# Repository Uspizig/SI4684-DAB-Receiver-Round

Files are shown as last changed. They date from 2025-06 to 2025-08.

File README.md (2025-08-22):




# Note:
The version in the repository is an ongoing development. It could and will contain bugs. To make sure you use the latest fully tested firmware, check the releases!

# Hint:
#define USE_HSPI_PORT ... set this to active in eTFT Lib user_setup.h. otherwise it won't work

# SI4684 DAB receiver
Advanced DAB Tuner software for Skyworks SI4684 tuner with ESP32 board and a round color LCD or AMOLED\
This is a fork of the famous PE5PVB SI4684 Project, unfinished and right now still in devolpment.
Check a more developed project on the origin source: https://www.pe5pvb.nl/

# How does it look

Simulation
<p align="center"> 
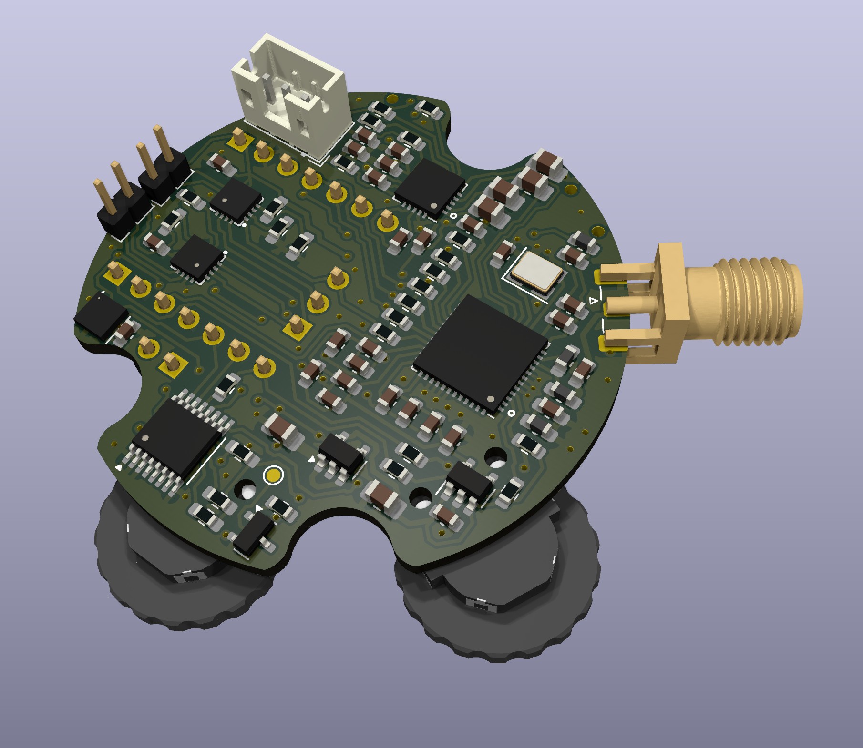
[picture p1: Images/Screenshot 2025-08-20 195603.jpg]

</p>

Real device
<p align="center"> 
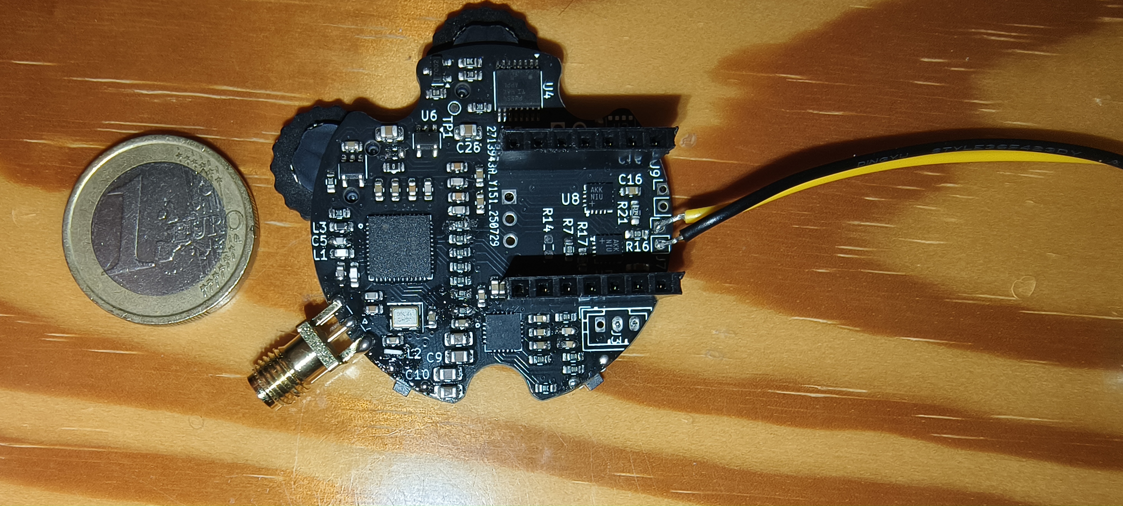
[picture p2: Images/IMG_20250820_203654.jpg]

</p>

# How does it look working

These are pictures of the very first HW bringup

<p align="center"> 
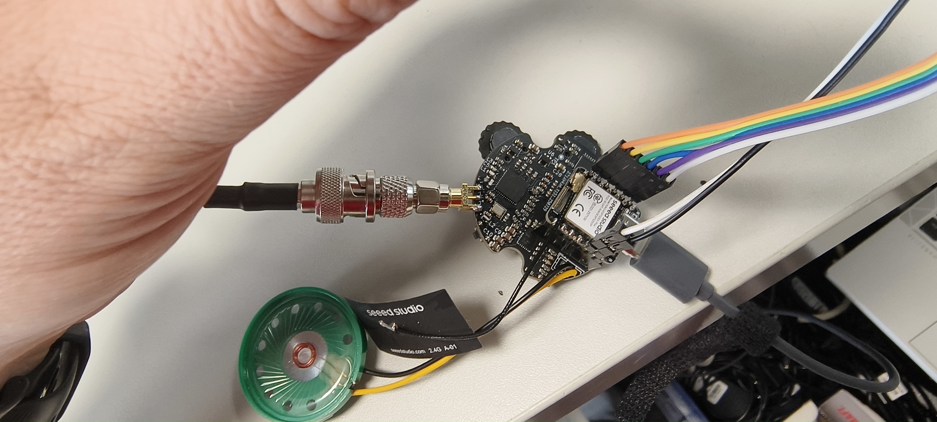
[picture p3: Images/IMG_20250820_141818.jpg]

</p>

Base Screen:
<p align="center"> 
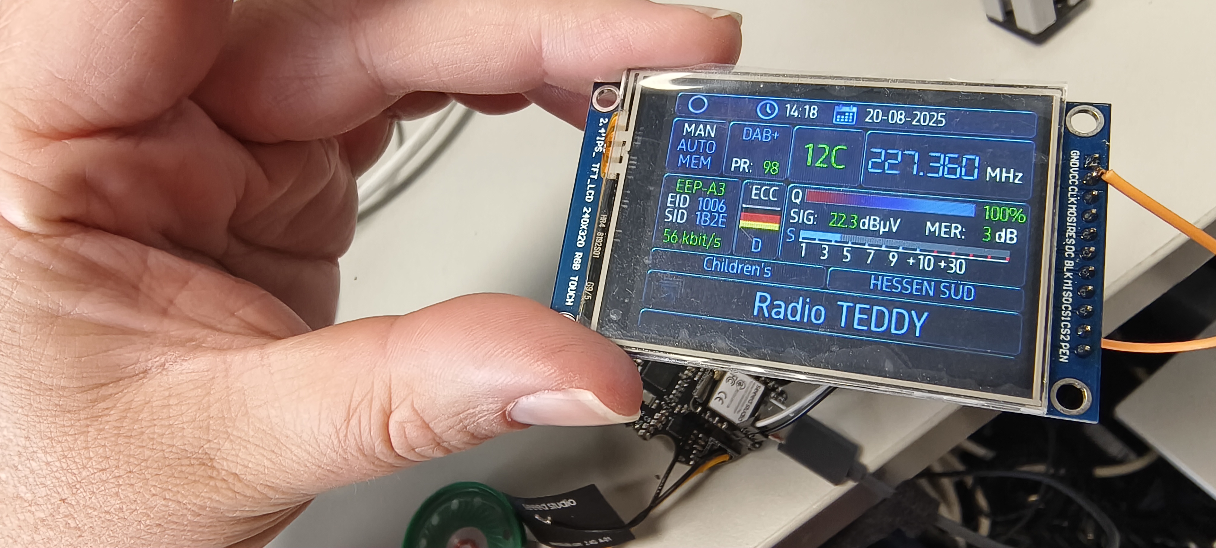
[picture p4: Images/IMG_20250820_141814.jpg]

</p>

DAB Slideshow
<p align="center"> 
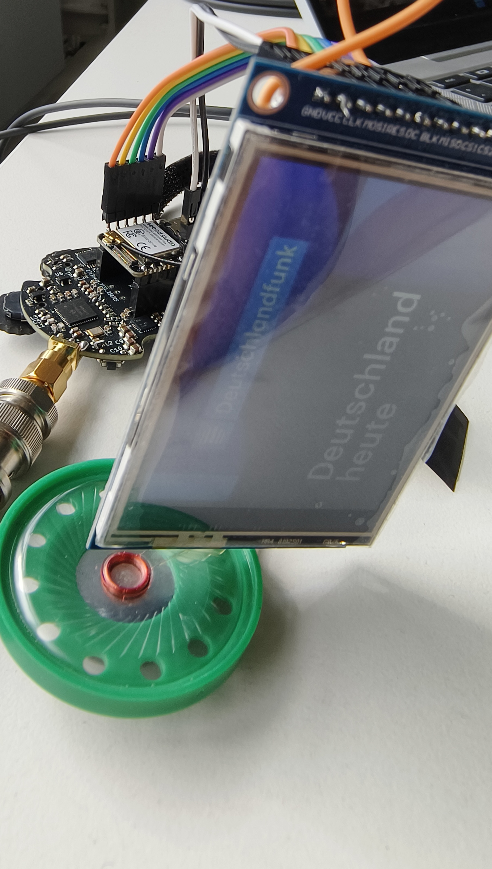
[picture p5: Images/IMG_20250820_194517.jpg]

</p>

# Libraries
These are the libraries used for this project:
- https://github.com/Bodmer/TFT_eSPI
- https://github.com/uzi18/TFT_eSPI
- https://github.com/Bodmer/JPEGDecoder
- https://github.com/bitbank2/PNGdec

Use these settings in the TFT_eSPI library:
```
#define ILI9341_2_DRIVER     // Alternative ILI9341 driver, see https://github.com/Bodmer/TFT_eSPI/issues/1172
#define TFT_WIDTH  240 // ST7789 240 x 240 and 240 x 320
#define TFT_HEIGHT 320 // ST7789 240 x 320

#define TFT_CS    38  // Chip select PIN
#define TFT_MISO  39  // MISO PIN
#define TFT_DC    40  // Data Command control pin
#define TFT_RST   41  // Reset pin (could connect 
#define TFT_MOSI  42  // MOSI PIN
#define TFT_SCLK  10  // CLK PIN
#define SPI_FREQUENCY  27000000
#define SMOOTH_FONT
#define USE_HSPI_PORT ///// THIS IS IMPORTANT OTHERWISE NO CONTACT TO DAB TUNER
#define LOAD_GFXFF  // FreeFonts. Include access to the 48 Adafruit_GFX free fonts FF1 to FF48 and custom fonts
#define SPI_READ_FREQUENCY  20000000
#define SPI_TOUCH_FREQUENCY  2500000

```
# Buttons
A brief instruction for the buttons:
- Top encoder: Choose frequency or memory channel
- Bottom encoder: Choose service or set headphones volume
- (Not in use right now) Top button: Short press: Service information, Long press: Stand-by mode. 
- Middle button: Short press: Set mode, Long press: Open menu.
- Lower button: Toggle Slideshow view.
  
## Contributing
I'm open for a new ideas in our project. Feel free to share your thoughts in 

You are using my software and you found a difficulty? Please create new [issue] and describe your problem.

I also would like to invite you to join our Discord community where we share our ideas and help each other with some issues.\
[Join the TEF6686 Discord community!](https://discord.gg/ZAVNdS74mC)  

Special thanks to all [contributors](https://github.com/PE5PVB/TEF-Nextion-Multiband/graphs/contributors). You are awesome! ❤️
## License
This program is free software; you can redistribute it and/or modify it under the terms of the GNU General Public License as published by the Free Software Foundation; either version 3 of the License, or (at your option) any later version.

This program is distributed in the hope that it will be useful, but WITHOUT ANY WARRANTY; without even the implied warranty of MERCHANTABILITY or FITNESS FOR A PARTICULAR PURPOSE. See the GNU General Public License for more details. 

## If you like this software. Contriubute to 


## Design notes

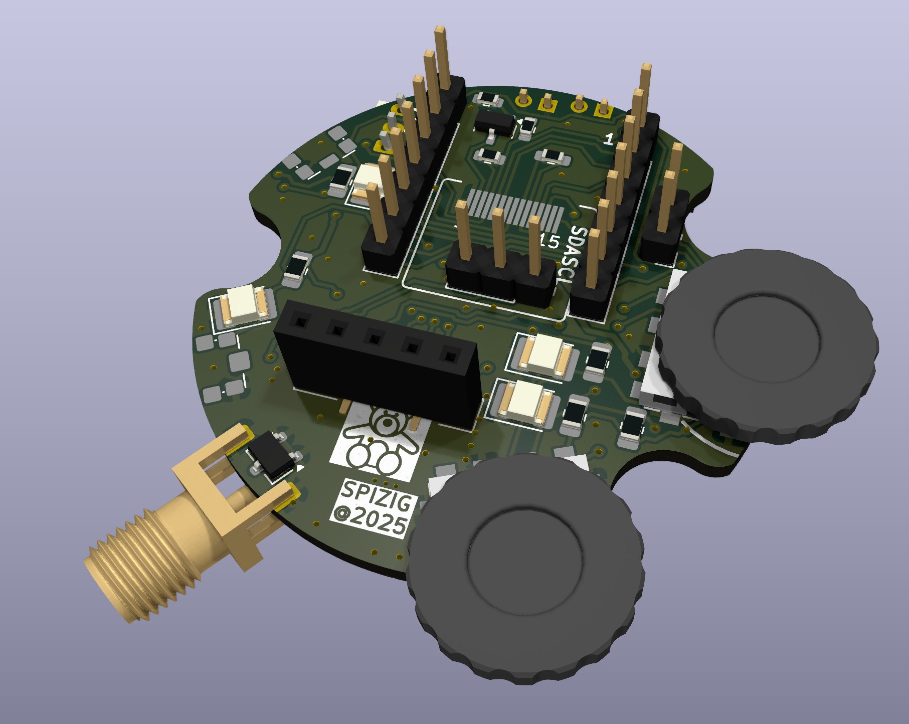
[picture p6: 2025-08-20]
Images/Screenshot 2025-08-20 195328.jpg

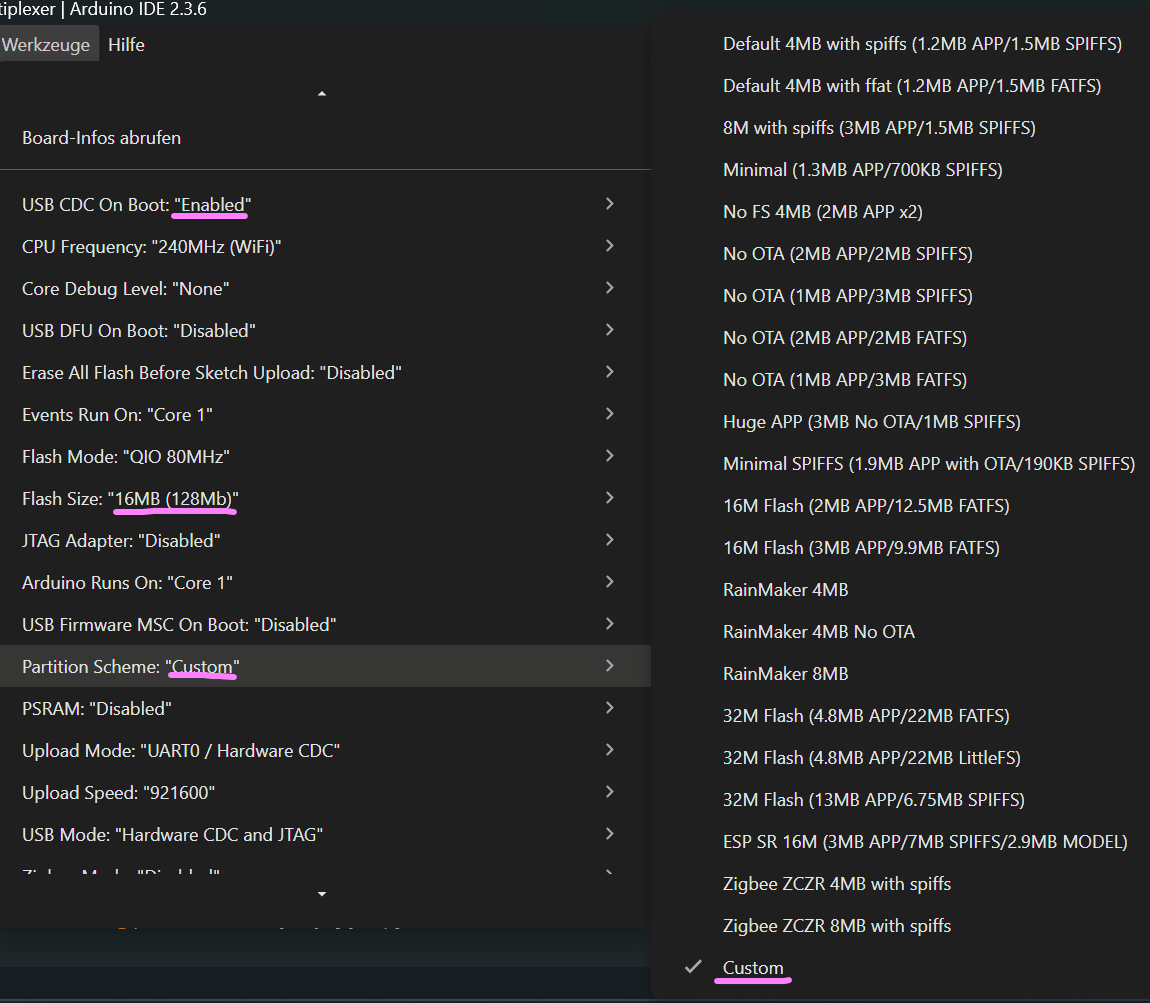
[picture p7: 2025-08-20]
Images/config.png

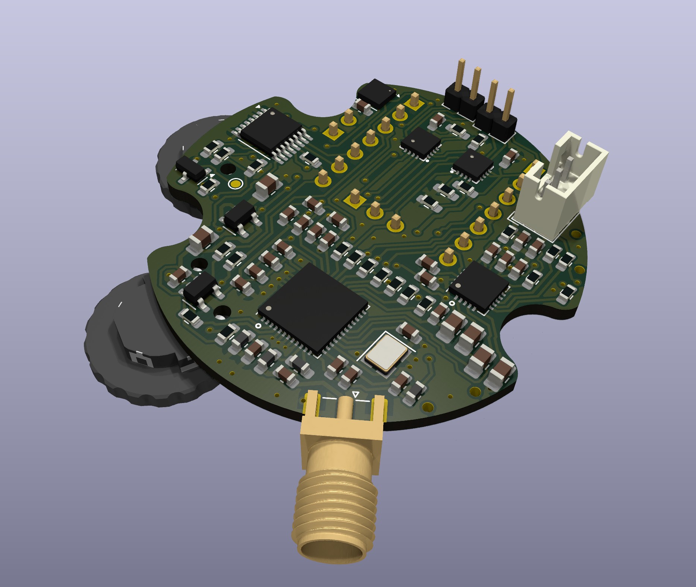
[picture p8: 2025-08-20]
Images/Screenshot 2025-08-20 195246.jpg

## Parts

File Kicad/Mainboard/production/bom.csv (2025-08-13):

Designator | Footprint | Quantity | Value | LCSC Part #
ANT | SMA_Samtec_SMA-J-P-H-ST-EM1_EdgeMount | 1 | Antenna_Shield
C1, C14, C15, C16, C17, C20, C26, C35, C4, C41 | 0603 | 10 | 1uF
C10, C11, C8, C9 | 0805 | 4 | 10uF
C12, C23, C29, C38 | 0603 | 4 | 8p2
C18, C19, C21, C24, C6 | 0603 | 5 | 100n
C22 | 0603 | 1 | 100nF
C25, C30, C40, C7 | 0603 | 4 | 2n2
C28, C31 | 0805 | 2 | 1uF
C3 | 0603 | 1 | 33p
C34, C39 | 0603 | 2 | 270p
C5 | 0603 | 1 | 2p7
D1 | SOT-23W | 1 | BAV99
D2, D3, D4, D5 | 1210 | 4 | LED
J1 | PinHeader_1x03_P2.54mm_Vertical | 1 | Conn_01x03
J2 | PinSocket_1x05_P2.54mm_Vertical_SMD_Pin1Left | 1 | Conn_01x05
J3 | JST_PH_B3B-PH-K_1x03_P2.00mm_Vertical | 1 | Headphones
J5 | PinHeader_1x07_P2.54mm_Vertical | 1 | DISP LEFT
J6 | PinHeader_1x07_P2.54mm_Vertical | 1 | DISP RIGHT
J7, J9 | PinHeader_1x02_P2.00mm_Vertical | 2 | Conn_01x02_Pin
J8 | PinHeader_1x02_P2.54mm_Vertical | 1 | Conn_01x02_Pin
L1 | 0603 | 1 | 18nH
L2 | 0603 | 1 | BEAD
L3 | 0603 | 1 | 120nH
L4 | 0603 | 1 | 22nH
Q1, Q2 | SOT-23 | 2 | 2N7002
R1, R18, R25, R26, R30, R31, R32, R34 | 0603 | 8 | 10k
R10, R11, R15, R2, R20, R3, R4, R5, R8, R9 | 0603 | 10 | 100
R12, R13 | 0603 | 2 | 2k
R14 | 0603 | 1 | 3k
R16, R7 | 0603 | 2 | 100K
R17 | 0603 | 1 | 680K
R19 | 0603 | 1 | 1M
R21 | 0603 | 1 | 330K
R22 | 0603 | 1 | 22
R27, R28, R29, R35, R36 | 0805 | 5 | 10k
R33, R37 | 0603 | 2 | 0R
R6 | 0603 | 1 | 600
SW5, SW6 | SW_SPST_CK_KMS2xxGP | 2 | SW_Push
TP1 | TestPoint_Pad_D1.0mm | 1 | TestPoint
U1 | SOT-23-5 | 1 | MIC5504-1.8YM5
U12, U14 | SW-SMD_SIQ-02FVS3_1 | 2 | SIQ-02FVS3
U13 | GC9A01_Touch_IPS_display_reversed_16pin | 1 | ~
U2 | Bosch_LGA-8_3x3mm_P0.8mm_ClockwisePinNumbering | 1 | BME688
U3 | QFN-48-1EP_7x7mm_P0.5mm_EP5.3x5.3mm | 1 | SI4684-A10-GM
U4 | TSSOP-16_4.4x5mm_P0.65mm | 1 | TCA9554PW
U5 | QFN-20-1EP_4x4mm_P0.5mm_EP2.7x2.7mm | 1 | TPA6130A2RTJTR | TPA6130A2RTJTR
U6 | SOT-23-5 | 1 | RT9013
U7, U8 | TQFN-16_L3.0-W3.0-P0.50-BL-EP1.5 | 2 | MAX98357AETE
X1 | Crystal_SMD_3225-4Pin_3.2x2.5mm | 1 | S3219200071060

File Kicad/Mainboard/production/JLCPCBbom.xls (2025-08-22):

Comment | Designator | Footprint | JLCPCB Part #
22nH | L4 | 0603 | C90207
RT9013 | U6 | SOT-23-5 | C47773
1uF | C28,C31 | 0805 | C28323
2n2 | C25,C30,C40,C7 | 0603 | C1604
MIC5504-1.8YM5 | U1 | SOT-23-5 | C626116
330K | R21 | 0603 | C23137
MAX98357AETE | U7,U8 | TQFN-16_L3.0-W3.0-P0.50-BL-EP1.5 | C910544
100n | C22,C18,C19,C21,C24,C6 | 0603 | C14663
SI4684-A10-GM | U3 | QFN-48-1EP_7x7mm_P0.5mm_EP5.3x5.3mm | C1526088
2N7002 | Q1 | SOT-23 | C8545
TPA6130A2RTJTR | U5 | QFN-20-1EP_4x4mm_P0.5mm_EP2.7x2.7mm | C130046
2k | R12,R13 | 0603 | C22975
10uF | C10,C11,C8,C9 | 0805 | C15850
600 | R6 | 0603 | C23204
S3219200071060 | X1 | Crystal_SMD_3225-4Pin_3.2x2.5mm | C426975
8p2 | C12,C23,C29,C38 | 0603 | C1685
680K | R17 | 0603 | C25822
100 | R10,R11,R15,R2,R20,R3,R4,R5,R8,R9 | 0603 | C22775
18nH | L1 | 0603 | C48590
TCA9554PW | U4 | TSSOP-16_4.4x5mm_P0.65mm | C477924
120nH | L3 | 0603 | C275354
33p | C3 | 0603 | C1663
1uF | C1,C14,C15,C16,C17,C20,C26,C35,C4,C41 | 0603 | C15849
10k | R1,R25,R26,R30,R31,R32 | 0603 | C25804
0R | R33,R37 | 0603 | C21189
100K | R16,R7 | 0603 | C25803

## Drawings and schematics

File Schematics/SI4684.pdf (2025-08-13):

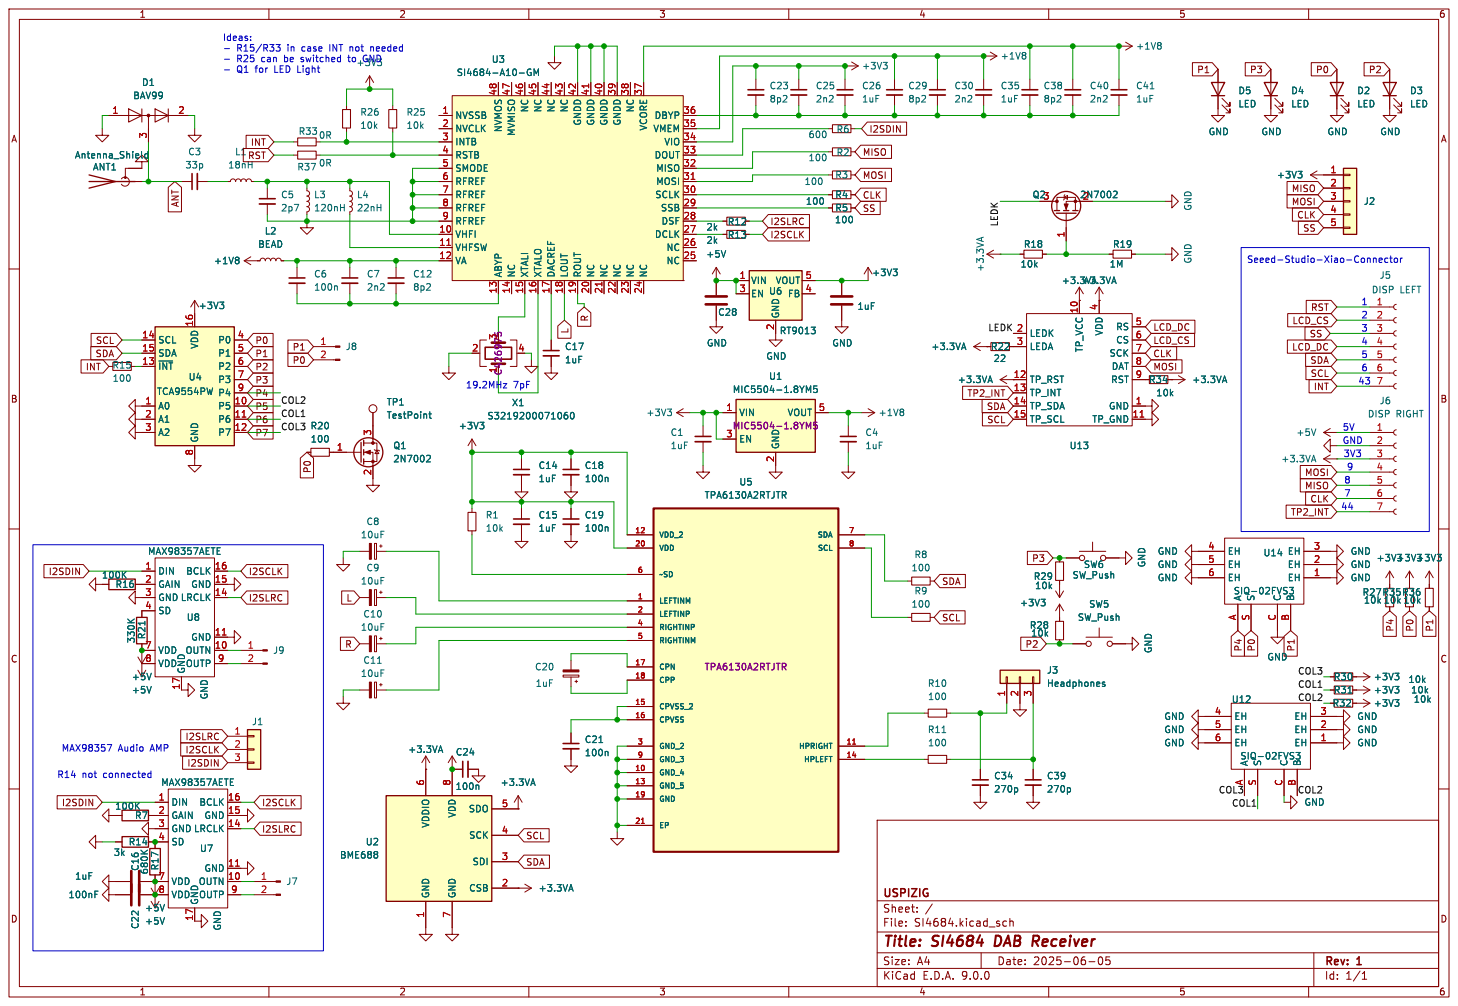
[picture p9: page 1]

J2 +1V8 TP1 TestPoint 1
- R25 can be switched to GND
- Q1 for LED Light

4 RS 5 CS 6 SCK 7 DAT 8 RST 9 GND 1 TP_GND 11 U13 R34 +3.3VA

4 RS 5 CS 6 SCK 7 DAT 8 RST 9 GND 1 TP_GND 11 R34 +3.3VA

B EH 3 EH 2 EH 1 U14 SIQ-02FVS3 GND

B EH 3 EH 2 EH 1 GND GND

B EH 3 EH 2 EH 1 U12SIQ-02FVS3 GND

B EH 3 EH 2 EH 1 GND

7 SDO 5 SCK 4 SDI 3 CSB 2 U2 BME688 C24

7 SDO 5 SCK 4 SDI 3 CSB 2 C24

Id: 1/1 Title: SI4684 DAB Receiver File: SI4684.kicad_sch Sheet: / USPIZIG

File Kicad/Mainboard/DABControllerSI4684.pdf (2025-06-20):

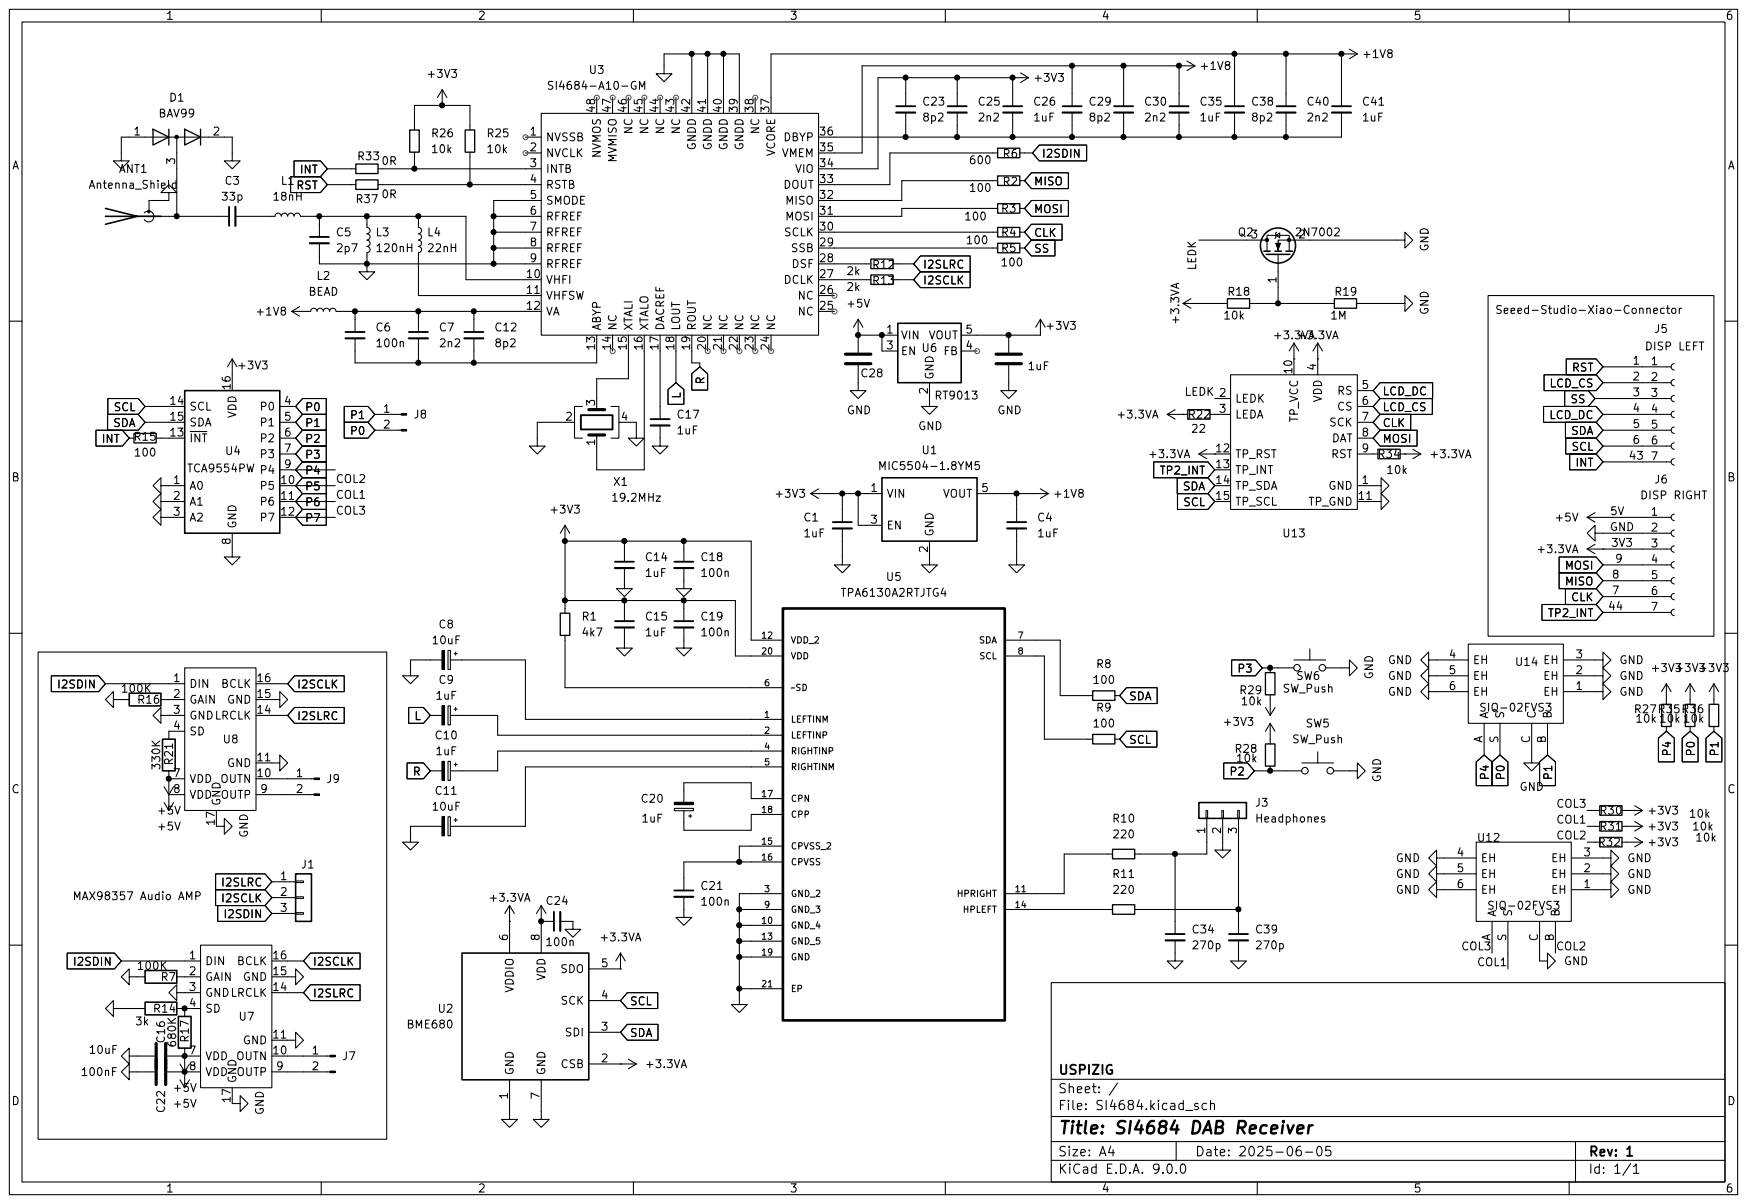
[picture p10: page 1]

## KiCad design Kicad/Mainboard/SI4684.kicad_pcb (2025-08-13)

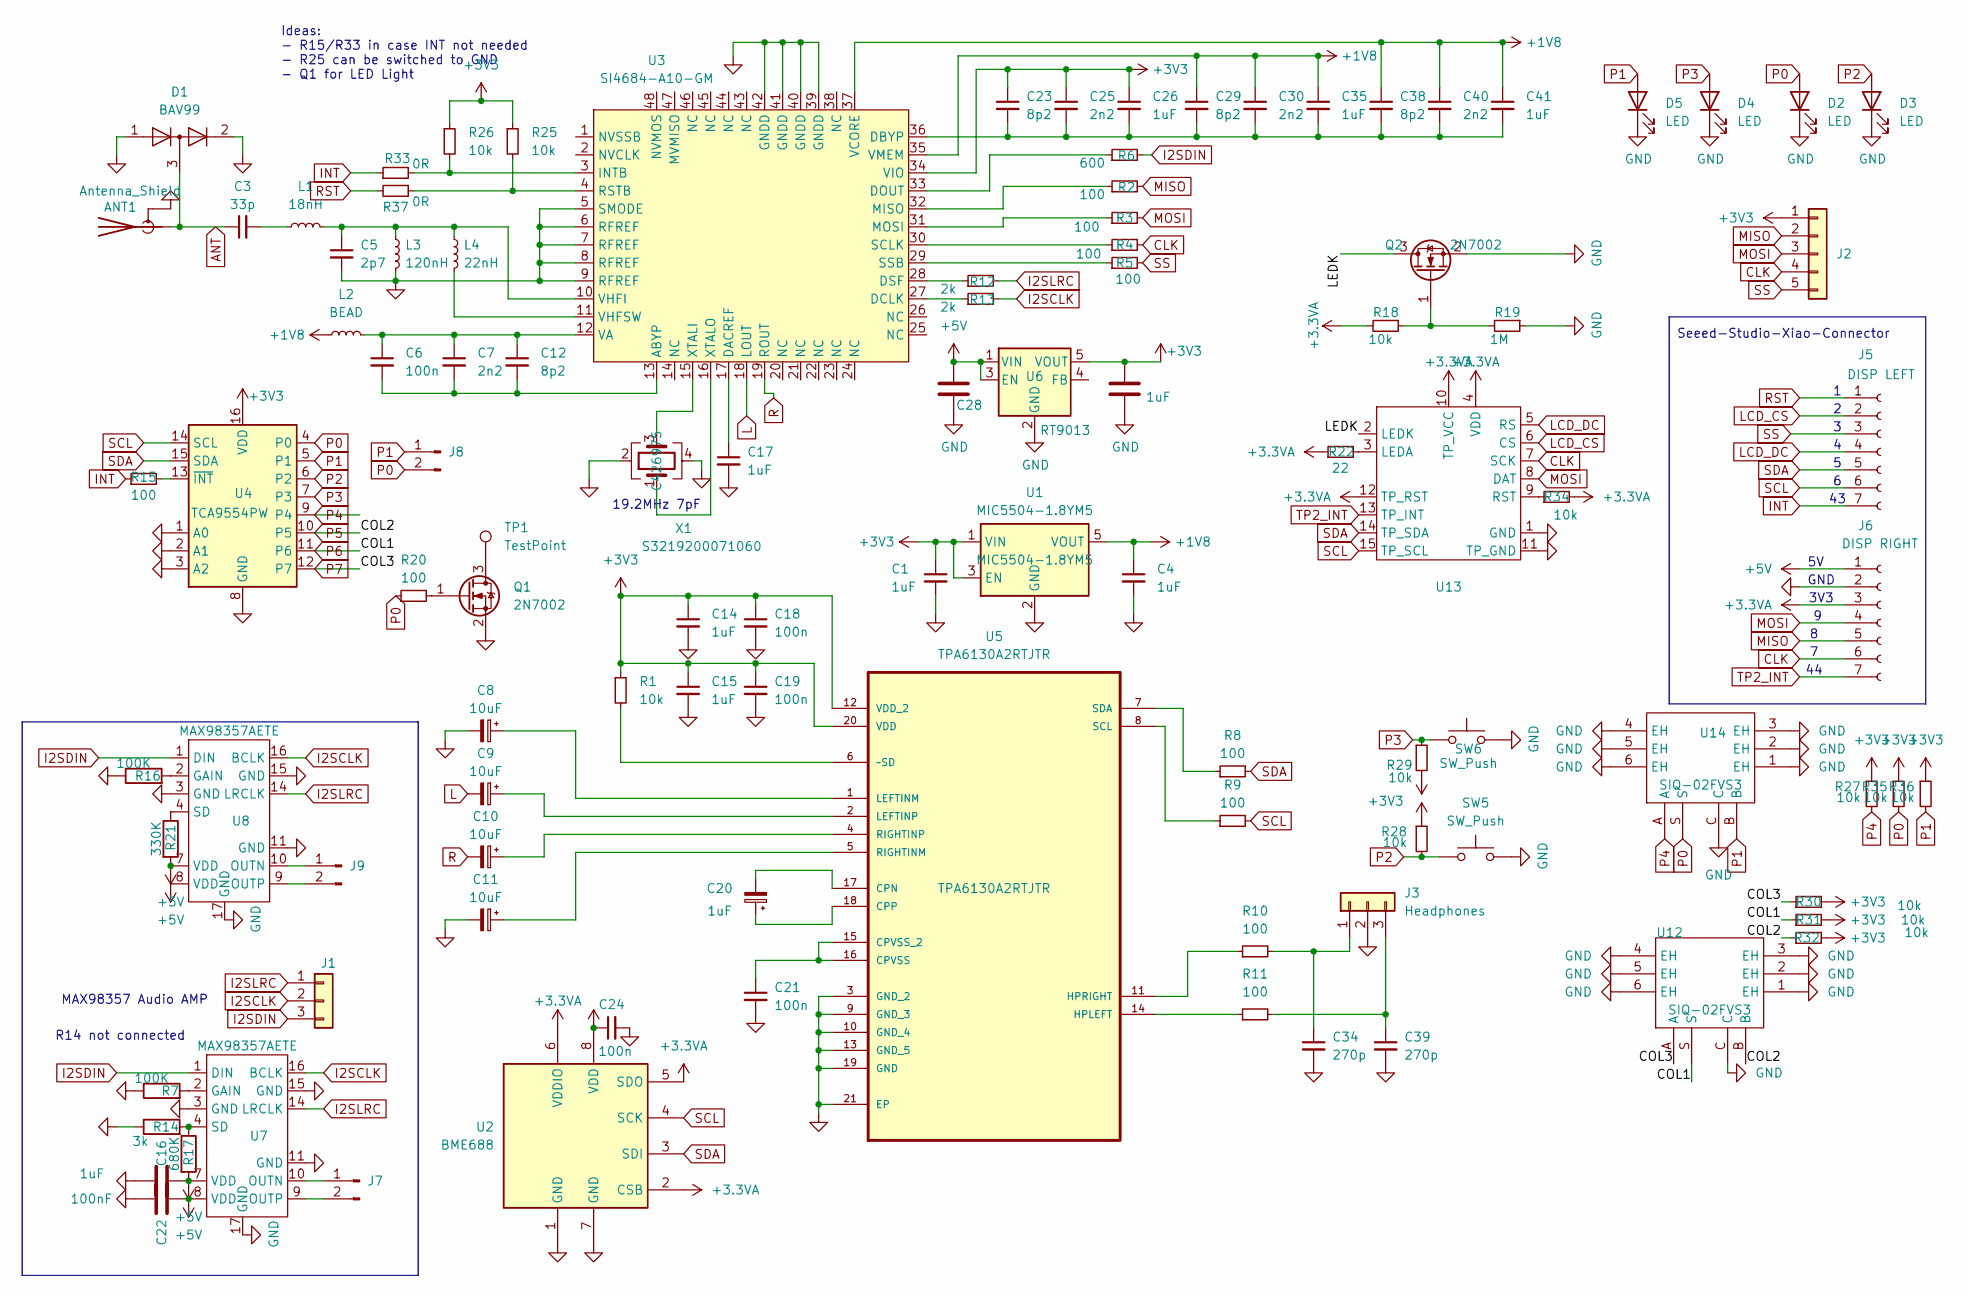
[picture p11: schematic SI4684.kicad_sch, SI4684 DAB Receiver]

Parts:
ANT1: Antenna_Shield; SMA_Samtec_SMA-J-P-H-ST-EM1_EdgeMount
C1, C4, C14, C15, C16, C17, C20, C26, C35, C41: 1uF; C_0603_1608Metric
C3: 33p; C_0603_1608Metric
C5: 2p7; C_0603_1608Metric_Pad1.08x0.95mm_HandSolder
C6, C18, C19, C21, C24: 100n; C_0603_1608Metric
C7, C25, C30, C40: 2n2; C_0603_1608Metric
C8, C9, C10, C11: 10uF; C_0805_2012Metric_Pad1.18x1.45mm_HandSolder
C12, C23, C29, C38: 8p2; C_0603_1608Metric
C22: 100nF; C_0603_1608Metric_Pad1.08x0.95mm_HandSolder
C28, C31: 1uF; C_0805_2012Metric_Pad1.18x1.45mm_HandSolder
C34, C39: 270p; C_0603_1608Metric
D1: BAV99; SOT-23W
D2, D4, D5: LED; LED_1210_3225Metric_Pad1.42x2.65mm_HandSolder
D3: LED; LED_1210_3225Metric
J1: Conn_01x03; PinHeader_1x03_P2.54mm_Vertical
J2: Conn_01x05; PinSocket_1x05_P2.54mm_Vertical_SMD_Pin1Left
J3: Headphones; JST_PH_B3B-PH-K_1x03_P2.00mm_Vertical
J5: DISP LEFT; PinHeader_1x07_P2.54mm_Vertical
J6: DISP RIGHT; PinHeader_1x07_P2.54mm_Vertical
J7, J9: Conn_01x02_Pin; PinHeader_1x02_P2.00mm_Vertical
J8: Conn_01x02_Pin; PinHeader_1x02_P2.54mm_Vertical
L1: 18nH; L_0603_1608Metric_Pad1.05x0.95mm_HandSolder
L2: BEAD; L_0603_1608Metric
L3: 120nH; L_0603_1608Metric_Pad1.05x0.95mm_HandSolder
L4: 22nH; L_0603_1608Metric_Pad1.05x0.95mm_HandSolder
Q1, Q2: 2N7002; SOT-23
R1, R18, R25, R26: 10k; R_0603_1608Metric
R2, R3, R4, R5, R8, R9, R10, R11, R15, R20: 100; R_0603_1608Metric
R6: 600; R_0603_1608Metric
R7, R16: 100K; R_0603_1608Metric_Pad0.98x0.95mm_HandSolder
R12, R13: 2k; R_0603_1608Metric
R14: 3k; R_0603_1608Metric_Pad0.98x0.95mm_HandSolder
R17: 680K; R_0603_1608Metric_Pad0.98x0.95mm_HandSolder
R19: 1M; R_0603_1608Metric
R21: 330K; R_0603_1608Metric_Pad0.98x0.95mm_HandSolder
R22: 22; R_0603_1608Metric
R27, R28, R29, R35, R36: 10k; R_0805_2012Metric_Pad1.20x1.40mm_HandSolder
R30, R31, R32, R34: 10k; R_0603_1608Metric_Pad0.98x0.95mm_HandSolder
R33, R37: 0R; R_0603_1608Metric
SW5, SW6: SW_Push; SW_SPST_CK_KMS2xxGP
TP1: TestPoint; TestPoint_Pad_D1.0mm
U1: MIC5504-1.8YM5; SOT-23-5
U2: BME688; Bosch_LGA-8_3x3mm_P0.8mm_ClockwisePinNumbering
U3: SI4684-A10-GM; QFN-48-1EP_7x7mm_P0.5mm_EP5.3x5.3mm
U4: TCA9554PW; TSSOP-16_4.4x5mm_P0.65mm
U5: TPA6130A2RTJTR; QFN-20-1EP_4x4mm_P0.5mm_EP2.7x2.7mm; MPN TPA6130A2RTJTR
U6: RT9013; SOT-23-5
U7, U8: MAX98357AETE; TQFN-16_L3.0-W3.0-P0.50-BL-EP1.5
U12, U14: SIQ-02FVS3; SW-SMD_SIQ-02FVS3_1; Manufacturer Part SIQ-02FVS3; LCSC Part Name 拨轮滚轮旋转编码器开关
U13: GC9A01_Touch_IPS_display_reversed_16pin
X1: S3219200071060; Crystal_SMD_3225-4Pin_3.2x2.5mm

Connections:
+1V8: C4.1, C29.1, C30.1, C35.1, C38.1, C40.1, C41.1, L2.1, U1.5 (VOUT), U3.35 (VMEM), U3.37 (VCORE)
+3.3VA: C24.1, J6.3, R18.2, R22.1, R34.2, U2.2 (CSB), U2.5 (SDO), U2.6 (VDDIO), U2.8 (VDD), U13.4 (VDD), U13.10 (TP_VCC), U13.12 (TP_RST)
+3V3: C1.1, C14.1, C15.1, C18.1, C19.1, C23.1, C25.1, C26.1, C31.2, J2.1, R1.1, R25.1, R26.1, R27.1, R28.1, R29.2, R30.2, R31.2, R32.2, R35.1, R36.1, U1.1 (VIN), U1.3 (EN), U3.34 (VIO), U4.16 (VDD), U5.12 (VDD_2), U5.20 (VDD), U6.5 (VOUT)
+5V: C16.1, C22.1, C28.2, J6.1, R17.2, R21.2, U6.1 (VIN), U6.3 (EN), U7.7 (VDD), U7.8 (VDD), U8.7 (VDD), U8.8 (VDD)
/LEDK: Q2.3 (D), U13.2 (LEDK)
ANT: ANT1.1 (A), C3.1, D1.3 (K); also elsewhere on the board
CLK: J2.4, J6.6, R4.2, U13.7 (SCK)
GND: ANT1.2 (Shield), C1.2, C4.2, C5.2, C8.2, C11.2, C14.2, C15.2, C16.2, C17.2, C18.2, C19.2, C21.2, C22.2, C24.2, C28.1, C31.1, C34.2, C39.2, D1.1 (K), D1.2 (A), D2.1 (K), D3.1 (K), D4.1 (K), D5.1 (K), J3.2, J6.2, L3.2, Q1.2 (S), Q2.2 (S), R7.1, R14.1, R16.1, R19.1, SW5.2, SW6.2, U1.2 (GND), U2.1 (GND), U2.7 (GND), U3.5 (SMODE), U3.6 (RFREF), U3.7 (RFREF), U3.8 (RFREF), U3.9 (RFREF), U3.39 (GNDD), U3.40 (GNDD), U3.41 (GNDD), U3.42 (GNDD), U3.49 (GND), U4.1 (A0), U4.2 (A1), U4.3 (A2), U4.8 (GND), U5.3 (GND_2), U5.9 (GND_3), U5.10 (GND_4), U5.13 (GND_5), U5.19 (GND), U5.21 (EP), U6.2 (GND), U7.3 (GND), U7.11 (GND), U7.15 (GND), U7.17 (GND), U8.3 (GND), U8.11 (GND), U8.15 (GND), U8.17 (GND), U12.1 (EH), U12.2 (EH), U12.3 (EH), U12.4 (EH), U12.5 (EH), U12.6 (EH), U12.C, U13.1 (GND), U13.11 (TP_GND), U14.1 (EH), U14.2 (EH), U14.3 (EH), U14.4 (EH), U14.5 (EH), U14.6 (EH), U14.C, X1.2, X1.4; also elsewhere on the board
I2SCLK: J1.2, R13.2, U7.16 (BCLK), U8.16 (BCLK)
I2SDIN: J1.3, R6.2, U7.1 (DIN), U8.1 (DIN)
I2SLRC: J1.1, R12.2, U7.14 (LRCLK), U8.14 (LRCLK)
INT: J5.7, R15.1, R33.1
L: C9.2, U3.18 (LOUT)
LCD_CS: J5.2, U13.6 (CS)
LCD_DC: J5.4, U13.5 (RS)
MISO: J2.2, J6.5, R2.2
MOSI: J2.3, J6.4, R3.2, U13.8 (DAT)
unnamed: C3.2, L1.1
unnamed: C34.1, J3.1, R10.2
unnamed: C39.1, J3.3, R11.2
unnamed: J7.1, U7.10 (OUTN)
unnamed: J7.2, U7.9 (OUTP)
unnamed: J9.1, U8.10 (OUTN)
unnamed: J9.2, U8.9 (OUTP)
unnamed: Q1.3 (D), TP1.1
unnamed: Q1.1 (G), R20.2
unnamed: Q2.1 (G), R18.1, R19.2
unnamed: C6.2, C7.2, C12.2, U3.13 (ABYP)
unnamed: C17.1, U3.17 (DACREF)
unnamed: C23.2, C25.2, C26.2, C29.2, C30.2, C35.2, C38.2, C40.2, C41.2, U3.36 (DBYP)
unnamed: R13.1, U3.27 (DCLK)
unnamed: R6.1, U3.33 (DOUT)
unnamed: R12.1, U3.28 (DSF)
unnamed: R26.2, R33.2, U3.3 (INTB)
unnamed: R2.1, U3.32 (MISO)
unnamed: R3.1, U3.31 (MOSI)
unnamed: R25.2, R37.1, U3.4 (RSTB)
unnamed: R4.1, U3.30 (SCLK)
unnamed: R5.1, U3.29 (SSB)
unnamed: C6.1, C7.1, C12.1, L2.2, U3.12 (VA)
unnamed: C5.1, L1.2, L3.1, L4.1, U3.10 (VHFI)
unnamed: L4.2, U3.11 (VHFSW)
unnamed: U3.15 (XTALI), X1.3
unnamed: U3.16 (XTALO), X1.1
unnamed: R15.2, U4.13 (~INT)
unnamed: C20.2, U5.17 (CPN)
unnamed: C20.1, U5.18 (CPP)
unnamed: C21.1, U5.15 (CPVSS_2), U5.16 (CPVSS)
unnamed: R11.1, U5.14 (HPLEFT)
unnamed: R10.1, U5.11 (HPRIGHT)
unnamed: C8.1, U5.1 (LEFTINM)
unnamed: C9.1, U5.2 (LEFTINP)
unnamed: C11.1, U5.5 (RIGHTINM)
unnamed: C10.1, U5.4 (RIGHTINP)
unnamed: R9.1, U5.8 (SCL)
unnamed: R8.1, U5.7 (SDA)
unnamed: R1.2, U5.6 (~SD)
unnamed: R7.2, U7.2 (GAIN)
unnamed: R14.2, R17.1, U7.4 (SD)
unnamed: R16.2, U8.2 (GAIN)
unnamed: R21.1, U8.4 (SD)
unnamed: R22.2, U13.3 (LEDA)
unnamed: R34.1, U13.9 (RST)
P0: D2.2 (A), J8.2, R20.1, R35.2, U4.4 (P0), U14.S
P1: D5.2 (A), J8.1, R36.2, U4.5 (P1), U14.B
P2: D3.2 (A), R28.2, SW5.1, U4.6 (P2)
P3: D4.2 (A), R29.1, SW6.1, U4.7 (P3)
P4: R27.2, U4.9 (P4), U14.A
P5: R32.1, U4.10 (P5), U12.B
P6: R31.1, U4.11 (P6), U12.S
P7: R30.1, U4.12 (P7), U12.A
R: C10.2, U3.19 (ROUT)
RST: J5.1, R37.2
SCL: J5.6, R9.2, U2.4 (SCK), U4.14 (SCL), U13.15 (TP_SCL)
SDA: J5.5, R8.2, U2.3 (SDI), U4.15 (SDA), U13.14 (TP_SDA)
SS: J2.5, J5.3, R5.2
TP2_INT: J6.7, U13.13 (TP_INT)

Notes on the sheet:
R14 not connected
MAX98357 Audio AMP
3V3
Seeed-Studio-Xiao-Connector
Ideas: - R15/R33 in case INT not needed - R25 can be switched to GND - Q1 for LED Light
19.2MHz 7pF
GND

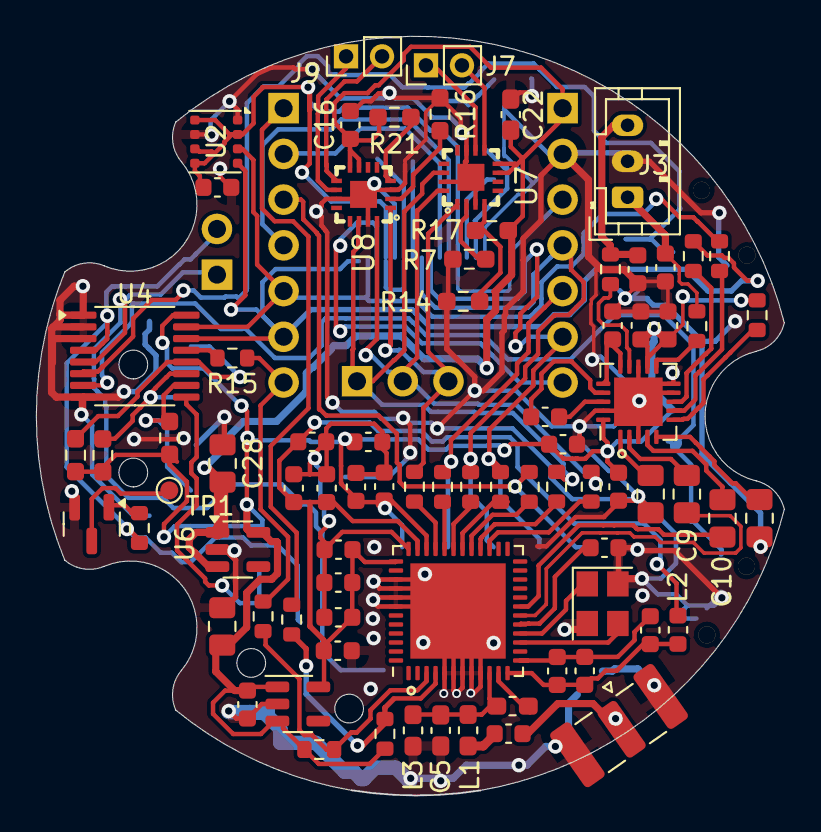
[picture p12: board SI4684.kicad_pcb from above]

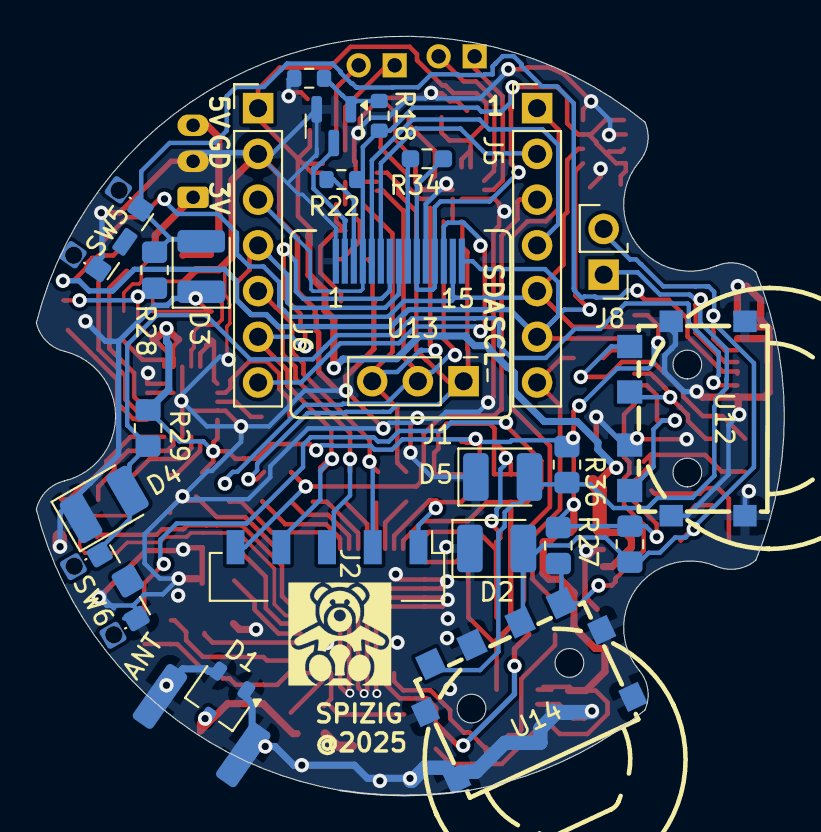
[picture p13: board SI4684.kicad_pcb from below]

Board: 2 copper layers, 41.6 x 42.2 mm, 105 parts (26 on the bottom side), 77 nets.

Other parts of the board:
ANT: Antenna_Shield; SMA_Samtec_SMA-J-P-H-ST-EM1_EdgeMount
H2: MountingHole; baerklein

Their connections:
ANT: ANT.1 (A); also elsewhere on the board
GND: ANT.2 (Shield); also elsewhere on the board

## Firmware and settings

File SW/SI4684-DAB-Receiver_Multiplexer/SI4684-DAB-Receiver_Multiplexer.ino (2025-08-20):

#include <TFT_eSPI.h>
#include <LittleFS.h>
#include <TimeLib.h>
#include "soc/soc.h"
#include "soc/rtc_cntl_reg.h"
#include <EEPROM.h>
#include <Wire.h>
#include "src/font.h"
#include "src/constants.h"
#include "src/graphics.h"
#include "src/language.h"
#include "src/gui.h"
#include "src/comms.h"
#include "src/slideshow.h"
#include "src/si4684.h"
#include "src/TPA6130A2.h"

TPA6130A2 Headphones;
DAB radio;

//uint8_t slaveSelectPin = 3;
uint8_t RESET_PIN = 1;
//uint8_t SDA = 5;
//uint8_t SCL = 6;

TFT_eSPI tft = TFT_eSPI(240, 320);

bool autoslideshow;
bool ChannelListView;
bool direction;
bool displayreset;
bool memorystore;
bool menu;
bool menuopen;
bool resetFontOnNextCall;
bool seek;
bool setupmode;
bool setvolume;
bool ShowServiceInformation;
bool SlideShowAvailableOld;
bool SlideShowView;
bool store;
bool trysetservice;
bool tuned;
bool tuning;
byte audiomodeold;
byte ContrastSet;
byte CurrentTheme;
byte dabfreq;
byte dabfreqold;
byte displayflip;
byte eccold;
byte ficold;
byte language;
byte memorypos;
byte memoryposold;
byte memoryposstatus;
byte ptyold;
byte rotarymode;
byte servicetypeold;
byte subnetclient;
byte tot;
byte tunemode;
byte unit;
byte volume;
char _serviceName[17];
const uint8_t* currentFont = nullptr;
int ActiveColor;
int ActiveColorSmooth;
int BackgroundColor;
int BackgroundColor2;
int BackgroundColor3;
int BackgroundColor4;
int BarInsignificantColor;
int BarSignificantColor;
int Bitrateupdatetimer;
int GreyoutColor;
int InsignificantColor;
int InsignificantColorSmooth;
int menuoption = ITEM1;
int PrimaryColor;
int PrimaryColorSmooth;
int rotary;
int rotary2;
int rssi;
int rssiold = 200;
int RTlengthold;
int RTWidth;
int SecondaryColor;
int SecondaryColorSmooth;
int SignalLevelold;
int SignificantColor;
int SignificantColorSmooth;
int SNRupdatetimer;
int xPos;
int16_t SAvg;
int16_t SAvg2;
int16_t SignalLevel;
int8_t CNR;
int8_t CNRold;
String clockstringOld;
String datestringOld;
String EIDold;
String EnsembleNameOld;
String dabfreqStringOld;
String ITUold;
String PLold;
String PSold;
String RTold;
String SIDold;
String SignalLeveloldString;
uint16_t BitrateOld;
uint32_t _serviceID;
uint8_t freq = 0;
uint8_t service = 0;
unsigned long tottimer;
unsigned long rssiTimer;
unsigned long rtticker;
unsigned long rttickerhold;
unsigned long TuningTimer;
unsigned long VolumeTimer;



// Encoder variables
volatile bool encoderChanged = false;

//int encoderPosition = 0;
int lastEncoderA = 0;
int lastEncoderB = 0;
bool lastButtonState = HIGH;
bool buttonPressed = false;


//int encoder2Position = 0;
int lastEncoder2A = 0;
int lastEncoder2B = 0;
bool lastButton2State = HIGH;
bool button2Pressed = false;


bool button3Pressed = false;
bool button4Pressed = false;
bool lastButton3State = HIGH;
bool lastButton4State = HIGH;

// Timing variables for debouncing
unsigned long lastDebounceTime = 0;
unsigned long debounceDelay = 50;

unsigned long lastDebounce2Time = 0;
unsigned long lastDebounce3Time = 0;
unsigned long lastDebounce4Time = 0;


/////

static const int8_t enc_states[]  = {0, -1, 1, 0, 1, 0, 0, -1, -1, 0, 0, 1, 0, 1, -1, 0};

typedef struct _Memory {
  byte      Channel;
  uint32_t  ServiceID;
  char      Label[17];
} DABMemory;

TFT_eSprite FullLineSprite = TFT_eSprite(&tft);
TFT_eSprite OneBigLineSprite = TFT_eSprite(&tft);
TFT_eSprite LongSprite = TFT_eSprite(&tft);
TFT_eSprite MediumSprite = TFT_eSprite(&tft);
TFT_eSprite ModeSprite = TFT_eSprite(&tft);
TFT_eSprite ShortSprite = TFT_eSprite(&tft);

DABMemory memory[EE_PRESETS_CNT];

void setup(void) {
  //WRITE_PERI_REG(RTC_CNTL_BROWN_OUT_REG, 0);
  /*gpio_set_drive_capability((gpio_num_t) 4, GPIO_DRIVE_CAP_0);
  gpio_set_drive_capability((gpio_num_t) 5, GPIO_DRIVE_CAP_0);
  gpio_set_drive_capability((gpio_num_t) 13, GPIO_DRIVE_CAP_0);
  gpio_set_drive_capability((gpio_num_t) 14, GPIO_DRIVE_CAP_0);
  gpio_set_drive_capability((gpio_num_t) 15, GPIO_DRIVE_CAP_0);
  gpio_set_drive_capability((gpio_num_t) 16, GPIO_DRIVE_CAP_0);
  gpio_set_drive_capability((gpio_num_t) 17, GPIO_DRIVE_CAP_0);
  gpio_set_drive_capability((gpio_num_t) 21, GPIO_DRIVE_CAP_0);
  gpio_set_drive_capability((gpio_num_t) 22, GPIO_DRIVE_CAP_0);*/
  setupmode = true;
  Serial.begin(115200);
  delay(1000);
  Serial.println("Hello World\n\n\n");
  if (!LittleFS.begin(true, "/littlefs", 10, "littlefs")){
    Serial.println("LittleFS mount failed. Formatting...");
    if (LittleFS.format()) {
        Serial.println("LittleFS successfully formatted.");
    } else {
        Serial.println("Error formatting LittleFS.");
    }
    if (!LittleFS.begin()) {
        Serial.println("LittleFS could not be mounted after formatting.");
    } else {
        Serial.println("LittleFS successfully mounted after formatting.");
    }
  } else {
    Serial.println("LittleFS successfully mounted.");
  }
  
  //bool begin(bool formatOnFail=false, const char * basePath="/littlefs", uint8_t maxOpenFiles=10, const char * partitionLabel="spiffs");
  

  
  

  pinMode(RESET_PIN, OUTPUT);
  digitalWrite(RESET_PIN, LOW);
  delay(500);
  digitalWrite(RESET_PIN, HIGH);

  if (LittleFS.exists("/temp.img")){ 
    LittleFS.remove("/temp.img");
    Serial.println("Little FS erased");
  }
  else{
    Serial.println("Little FS not erased");
  }

  EEPROM.begin(EE_TOTAL_CNT);
  if (EEPROM.readByte(EE_BYTE_CHECKBYTE) != EE_CHECKBYTE_VALUE) DefaultSettings();
  ContrastSet = EEPROM.readByte(EE_BYTE_CONTRASTSET);
  language = EEPROM.readByte(EE_BYTE_LANGUAGE);
  displayflip = EEPROM.readByte(EE_BYTE_DISPLAYFLIP);
  rotarymode = EEPROM.readByte(EE_BYTE_ROTARYMODE);
  tunemode = EEPROM.readByte(EE_BYTE_TUNEMODE);
  unit = EEPROM.readByte(EE_BYTE_UNIT);
  dabfreq = EEPROM.readByte(EE_BYTE_DABFREQ);
  volume = EEPROM.readByte(EE_BYTE_VOLUME);
  memorypos = EEPROM.readByte(EE_BYTE_MEMORYPOS);
  autoslideshow = EEPROM.readByte(EE_BYTE_AUTOSLIDESHOW);
  tot = EEPROM.readByte(EE_BYTE_TOT);
  CurrentTheme = EEPROM.readByte(EE_BYTE_THEME);
  radio.BufferSlideShow = EEPROM.readByte(EE_BYTE_BUFFERSLIDESHOW);

  for (int i = 0; i < EE_PRESETS_CNT; i++) {
    memory[i].Channel = EEPROM.readByte(i + EE_PRESETS_FREQ_START);
    EEPROM.get((i * 8) + EE_PRESETS_SERVICEID_START, memory[i].ServiceID);
    for (int y = 0; y < 16; y++) {
      memory[i].Label[y] = EEPROM.readByte((i * 17) + y + EE_PRESETS_NAME_START);
    }
    memory[i].Label[16] = '\0';
  }

  Headphones.Init();
  delay(50);
  Headphones.SetHiZ(0);
  delay(50);
  Headphones.SetVolume(volume);

  tft.init();
  tft.initDMA();
  doTheme();
  if (displayflip == 0) tft.setRotation(3); else tft.setRotation(1);

  /*pinMode(STANDBYBUTTON, INPUT);
  pinMode(MODEBUTTON, INPUT);
  pinMode(SLBUTTON, INPUT);
  pinMode(ROTARY_BUTTON, INPUT);
  pinMode(ROTARY_BUTTON2, INPUT);
  pinMode(ROTARY_PIN_A, INPUT);
  pinMode(ROTARY_PIN_B, INPUT);
  pinMode(ROTARY_PIN_2A, INPUT);
  pinMode(ROTARY_PIN_2B, INPUT);
  attachInterrupt(digitalPinToInterrupt(ROTARY_PIN_A), read_encoder, CHANGE);
  attachInterrupt(digitalPinToInterrupt(ROTARY_PIN_B), read_encoder, CHANGE);
  attachInterrupt(digitalPinToInterrupt(ROTARY_PIN_2A), read_encoder2, CHANGE);
  attachInterrupt(digitalPinToInterrupt(ROTARY_PIN_2B), read_encoder2, CHANGE);*/

  // Initialize TCA9554 Button Controller
  // Initialize interrupt pin
  pinMode(INT_PIN, INPUT_PULLUP);
  attachInterrupt(digitalPinToInterrupt(INT_PIN), encoderISR, FALLING);
  if (initTCA9554()) {
    Serial.println("TCA9554 initialized successfully");
  } else {
    Serial.println("Failed to initialize TCA9554");
    while(1); // Halt if initialization fails
  }
  
  // Read initial encoder state
  uint8_t initialState = readTCA9554();
  lastEncoderA = (initialState >> ENCODER_A_PIN) & 1;
  lastEncoderB = (initialState >> ENCODER_B_PIN) & 1;
  lastButtonState = (initialState >> ENCODER_BTN_PIN) & 1;

  lastEncoder2A = (initialState >> ENCODER2_A_PIN) & 1;
  lastEncoder2B = (initialState >> ENCODER2_B_PIN) & 1;
  lastButton2State = (initialState >> ENCODER2_BTN_PIN) & 1;

  lastButton3State = (initialState >> ENCODER_BTN3_PIN) & 1;
  lastButton4State = (initialState >> ENCODER_BTN4_PIN) & 1;
  
  Serial.println("Rotary Encoder with TCA9554 Ready");
  Serial.println("Turn encoder or press button...");




  tft.setSwapBytes(true);
  tft.fillScreen(BackgroundColor);

  OneBigLineSprite.createSprite(270, 30);
  OneBigLineSprite.setSwapBytes(true);

  ShortSprite.createSprite(36, 16);
  ShortSprite.setSwapBytes(true);

  MediumSprite.createSprite(70, 16);
  MediumSprite.setSwapBytes(true);

  LongSprite.createSprite(150, 17);
  LongSprite.setSwapBytes(true);

  FullLineSprite.createSprite(308, 20);
  FullLineSprite.setSwapBytes(true);

  ModeSprite.createSprite(46, 47);
  ModeSprite.setTextDatum(TC_DATUM);
  ModeSprite.setSwapBytes(true);

  loadFonts(true);
/*
  if (digitalRead(SLBUTTON) == LOW && digitalRead(ROTARY_BUTTON) == HIGH) {
    if (rotarymode == 0) rotarymode = 1; else rotarymode = 0;
    EEPROM.writeByte(EE_BYTE_ROTARYMODE, rotarymode);
    EEPROM.commit();

    analogWrite(CONTRASTPIN, ContrastSet * 2 + 27);
    tftPrint(0, myLanguage[language][1], 155, 70, ActiveColor, ActiveColorSmooth, 28);
    tftPrint(0, myLanguage[language][2], 155, 130, ActiveColor, ActiveColorSmooth, 28);
    while (digitalRead(SLBUTTON) == LOW);
  }

  if (digitalRead(MODEBUTTON) == LOW) {
    if (displayflip == 0) {
      displayflip = 1;
      tft.setRotation(1);
    } else {
      displayflip = 0;
      tft.setRotation(3);
    }
    EEPROM.writeByte(EE_BYTE_DISPLAYFLIP, displayflip);
    EEPROM.commit();

    analogWrite(CONTRASTPIN, ContrastSet * 2 + 27);
    tftPrint(0, myLanguage[language][3], 155, 70, ActiveColor, ActiveColorSmooth, 28);
    tftPrint(0, myLanguage[language][2], 155, 130, ActiveColor, ActiveColorSmooth, 28);
    while (digitalRead(MODEBUTTON) == LOW);
  }

  if (digitalRead(ROTARY_BUTTON) == LOW && digitalRead(SLBUTTON) == LOW) {
    DefaultSettings();

    analogWrite(CONTRASTPIN, ContrastSet * 2 + 27);
    tftPrint(0, myLanguage[language][10], 155, 70, ActiveColor, ActiveColorSmooth, 28);
    tftPrint(0, myLanguage[language][2], 155, 130, ActiveColor, ActiveColorSmooth, 28);
    while (digitalRead(ROTARY_BUTTON) == LOW && digitalRead(SLBUTTON) == LOW);
    ESP.restart();
  }*/

  tft.pushImage (0, 0, 320, 240, SplashScreen);
  tftPrint(0, myLanguage[language][72], 155, 15, ActiveColor, ActiveColorSmooth, 28);

  tftPrint(0, String(myLanguage[language][9]) + " " + String(VERSION), 160, 190, TFT_WHITE, TFT_DARKGREY, 16);

  for (int x = 0; x <= ContrastSet; x++) {
    analogWrite(CONTRASTPIN, x * 2 + 27);
    delay(30);
  }

  
  Serial.println("Before Radio Begin");
  if (radio.begin(3)) {
    tftPrint(0, String(radio.getChipID()) + " v" + String(radio.getFirmwareVersion()), 160, 210, TFT_WHITE, TFT_DARKGREY, 16);
    Serial.println("Chip responded");
  } else {
    tftPrint(0, myLanguage[language][77], 160, 210, TFT_WHITE, TFT_DARKGREY, 16);
    Serial.println("NO Radio Chip detected");
    delay(2000);
    Serial.println("TEST");
    for (;;);
  }

  delay(1500);

  if (tunemode == TUNE_MEM && !IsStationEmpty()) {
    DoMemoryPosTune();
  } else {
    if (tunemode == TUNE_MEM) tunemode = TUNE_MAN;
    radio.setFreq(dabfreq);
    EEPROM.get(EE_UINT32_SERVICEID, _serviceID);
    for (int i = 0; i < 16; i++) {
      _serviceName[i] = EEPROM.readByte(i + EE_CHAR17_SERVICENAME);
    }
  }
  if (_serviceID != 0 ) trysetservice = true;

  BuildDisplay();
  setupmode = false;
  tottimer = millis();
}

void loop(void) {
  ProcessDAB();
  Communication();
  displayreset = false;

  if (encoderChanged) {
    encoderChanged = false;
    handleEncoderChange();
  }

  if (seek) Seek(direction);

  if (tot != 0) {
    unsigned long totprobe = tot * 60000;
    if (millis() >= tottimer + totprobe) deepSleep();
  }


// Rotary Encoder Auswertung Rotary 1
  if (millis() >= TuningTimer + 500) {
    if (store) {
      //detachInterrupt(digitalPinToInterrupt(ROTARY_PIN_A));
      //detachInterrupt(digitalPinToInterrupt(ROTARY_PIN_B));
      StoreFrequency();
      store = false;
      //attachInterrupt(digitalPinToInterrupt(ROTARY_PIN_A), read_encoder, CHANGE);
      //attachInterrupt(digitalPinToInterrupt(ROTARY_PIN_B), read_encoder, CHANGE);
    } else if (tuning) {
      radio.setFreq(dabfreq);
      tuning = false;
      if (tunemode == TUNE_MEM) trysetservice = true;
    }
  }

  if (millis() >= VolumeTimer + 3000 && setvolume) {
    closeVolume();
  }

//Rortary 2 Auswerung
  if (!menu) {
    if (rotary2 == -1) KeyUp2();
    if (rotary2 == 1) KeyDown2();
  }
//Rotary 1 Auswertung
  if (rotary == -1) KeyUp();
  if (rotary == 1) KeyDown();

//Buttons Auswertung
  //if (digitalRead(MODEBUTTON) == LOW) ModeButtonPress();
  if (button3Pressed && (millis() - lastDebounce3Time) > debounceDelay){ModeButtonPress();button3Pressed = false;}
  
  //if (!menu && digitalRead(SLBUTTON) == LOW) SlideShowButtonPress();
  if (!menu && button4Pressed && (millis() - lastDebounce4Time) > debounceDelay) {SlideShowButtonPress();button4Pressed = false;}
  
  //if (!menu && digitalRead(STANDBYBUTTON) == LOW) StandbyButtonPress();
//Rotary Button 1 Auswertung
  //if (digitalRead(ROTARY_BUTTON) == LOW) ButtonPress();
  if (buttonPressed && (millis() - lastDebounceTime) > debounceDelay){ButtonPress();buttonPressed = false;}
//Rotary Button 2 Auswertung
  //if (!menu && digitalRead(ROTARY_BUTTON2) == LOW) Button2Press();
  if (!menu &&  button2Pressed && (millis() - lastDebounce2Time) > debounceDelay){Button2Press();button2Pressed = false;}
}

void ProcessDAB(void) {
  if (!tuning) {
    radio.Update();
    SignalLevel = radio.getRSSI();
  }

  if (radio.panic()) doRecovery();

  if (trysetservice && radio.signallock) {
    for (byte x = 0; x < radio.numberofservices; x++) {
      if (_serviceID == radio.service[x].ServiceID) {
        radio.setService(x);
        radio.ServiceStart = true;
        trysetservice = false;
        store = true;
      }
    }
  }

  if (!SlideShowView && !menu) {
    if (!ChannelListView) ShowSignalLevel();
    ShowRT();
    if (!ShowServiceInformation && !ChannelListView) {
      if (autoslideshow && radio.SlideShowAvailable && radio.SlideShowUpdate) {
        SlideShowButtonPress();
      } else {
        ShowBitrate();
        ShowEID();
        ShowSID();
        ShowPTY();
        ShowProtectionlevel();
        ShowPS();
        ShowEN();
        ShowAudioMode();
        ShowClock();
        ShowSlideShowIcon();
        ShowECC();
      }
    }
  } else {
    if (radio.SlideShowAvailable && radio.SlideShowUpdate && !menu) {
      ShowSlideShow();
      radio.SlideShowUpdate = false;
    }
  }
}

void closeVolume(void) {
  if (ChannelListView) {
    BuildChannelList();
  } else if (ShowServiceInformation) {
    ShowServiceInfo();
  } else if (SlideShowView) {
    SlideShowView = false;
    SlideShowButtonPress();
  } else {
    BuildDisplay();
  }
}

void doRecovery(void) {
  radio.begin(3);
  radio.setFreq(dabfreq);
  trysetservice = true;
}

void DABSelectService(bool dir) {
  if (radio.numberofservices > 0) {
    bool hasValidService = false;
    for (int i = 0; i < radio.numberofservices; i++) {
      if (radio.service[i].ServiceType == 0x00 ||
          radio.service[i].ServiceType == 0x04 ||
          radio.service[i].ServiceType == 0x05) {
        hasValidService = true;
        break;
      }
    }

    if (!hasValidService) return;

    if (dir) {
      radio.ServiceIndex = (radio.ServiceIndex + 1) % radio.numberofservices;
    } else {
      radio.ServiceIndex = (radio.ServiceIndex == 0) ? (radio.numberofservices - 1) : (radio.ServiceIndex - 1);
    }

    while (radio.service[radio.ServiceIndex].ServiceType != 0x00 &&
           radio.service[radio.ServiceIndex].ServiceType != 0x04 &&
           radio.service[radio.ServiceIndex].ServiceType != 0x05) {
      if (dir) {
        radio.ServiceIndex = (radio.ServiceIndex + 1) % radio.numberofservices;
      } else {
        radio.ServiceIndex = (radio.ServiceIndex == 0) ? (radio.numberofservices - 1) : (radio.ServiceIndex - 1);
      }
    }

    radio.setService(radio.ServiceIndex);
    radio.ServiceStart = true;
    store = true;
  }
}

void StoreFrequency(void) {
  EEPROM.put(EE_UINT32_SERVICEID, radio.service[radio.ServiceIndex].ServiceID);
  EEPROM.put(EE_BYTE_DABFREQ, dabfreq);
  for (int i = 0; i < 16; i++) {
    EEPROM.writeByte(i + EE_CHAR17_SERVICENAME, radio.PStext[i]);
  }
  EEPROM.commit();
  _serviceID = radio.service[radio.ServiceIndex].ServiceID;
}

void ButtonPress(void) {
  tottimer = millis();
  if (!menu) {
    if (tunemode == TUNE_MEM) {
      if (!memorystore) {
        memorystore = true;
        if (!IsStationEmpty()) memoryposstatus = MEM_EXIST;
        else memoryposstatus = MEM_NORMAL;
        ShowMemoryPos();
        ShowTuneMode();
      } else {
        memorystore = false;
        EEPROM.writeByte(memorypos + EE_PRESETS_FREQ_START, dabfreq);
        EEPROM.put((memorypos * 8) + EE_PRESETS_SERVICEID_START, radio.service[radio.ServiceIndex].ServiceID);
        for (int x = 0; x < 16; x++) {
          char character = radio.service[radio.ServiceIndex].Label[x];
          EEPROM.writeByte((memorypos * 17) + x + EE_PRESETS_NAME_START, character);
          memory[memorypos].Label[x] = character;
        }
        EEPROM.writeByte((memorypos * 17) + 16 + EE_PRESETS_NAME_START, '\0');
        memory[memorypos].Label[16] = '\0';
        memory[memorypos].Channel = dabfreq;
        memory[memorypos].ServiceID = radio.service[radio.ServiceIndex].ServiceID;
        EEPROM.commit();

        ShowTuneMode();
        if (memoryposstatus == MEM_DARK || memoryposstatus == MEM_EXIST) {
          memoryposstatus = MEM_NORMAL;
          ShowMemoryPos();
        }
      }
    } else {
      if (ChannelListView || SlideShowView || ShowServiceInformation) {
        BuildDisplay();
      } else {
        ChannelListView = true;
        BuildChannelList();
      }
    }
  } else {
    DoMenu();
  }
  //while (digitalRead(ROTARY_BUTTON) == LOW);
}

void Button2Press(void) {
  memorystore = false;
  memoryposstatus = MEM_NORMAL;
  tottimer = millis();
  if (setvolume) {
    closeVolume();
  } else {
    setvolume = true;
    ShowVolume();
  }
  //while (digitalRead(ROTARY_BUTTON2) == LOW);
}

void SlideShowButtonPress(void) {
  setvolume = false;
  memorystore = false;
  memoryposstatus = MEM_NORMAL;
  if (!SlideShowView && radio.SlideShowAvailable) {
    tft.fillScreen(TFT_BLACK);
    radio.SlideShowUpdate = true;
    SlideShowView = true;
    ShowServiceInformation = false;
  } else {
    if (SlideShowView) BuildDisplay();
    SlideShowView = false;
  }
  //while (digitalRead(SLBUTTON) == LOW);
}

void ModeButtonPress(void) {
  tottimer = millis();
  seek = false;
  unsigned long counterold = millis();
  unsigned long counter = millis();
  //while (digitalRead(MODEBUTTON) == LOW && counter - counterold <= 1000) counter = millis(); //USPIZIG Hier Problem

  if (menu) {
    EEPROM.writeByte(EE_BYTE_LANGUAGE, language);
    EEPROM.writeByte(EE_BYTE_CONTRASTSET, ContrastSet);
    EEPROM.writeByte(EE_BYTE_AUTOSLIDESHOW, autoslideshow);
    EEPROM.writeByte(EE_BYTE_UNIT, unit);
    EEPROM.writeByte(EE_BYTE_TOT, tot);
    EEPROM.writeByte(EE_BYTE_THEME, CurrentTheme);
    EEPROM.writeByte(EE_BYTE_BUFFERSLIDESHOW, radio.BufferSlideShow);
    EEPROM.commit();
    menu = false;
    BuildDisplay();
  } else if (SlideShowView || ChannelListView || ShowServiceInformation) {
    BuildDisplay();
  } else {
    memorystore = false;
    memoryposstatus = MEM_NORMAL;

    if (counter - counterold <= 1000) {
      tunemode++;
      if (tunemode > 2) tunemode = 0;
      ShowTuneMode();
      ShowMemoryPos();
    } else {
      menu = true;
      BuildMenu();

    }
  }
  //while (digitalRead(MODEBUTTON) == LOW);
}

void StandbyButtonPress(void) {
  tottimer = millis();
  unsigned long counterold = millis();
  unsigned long counter = millis();
  if (memorystore) {
    EEPROM.writeByte(memorypos + EE_PRESETS_FREQ_START, EE_PRESETS_FREQUENCY);
    EEPROM.put((memorypos * 8) + EE_PRESETS_SERVICEID_START, 0);
    for (int x = 0; x < 16; x++) {
      EEPROM.writeByte((memorypos * 17) + x + EE_PRESETS_NAME_START, '\0');
      memory[memorypos].Label[x] = '\0';
    }
    EEPROM.writeByte((memorypos * 17) + 16 + EE_PRESETS_NAME_START, '\0');
    memory[memorypos].Label[16] = '\0';
    memory[memorypos].Channel = EE_PRESETS_FREQUENCY;
    memory[memorypos].ServiceID = 0;
    EEPROM.commit();
    memorystore = false;
    ShowTuneMode();
    if (memoryposstatus == MEM_DARK || memoryposstatus == MEM_EXIST) {
      memoryposstatus = MEM_NORMAL;
      ShowMemoryPos();
    }
  } else {
    while (digitalRead(STANDBYBUTTON) == LOW && counter - counterold <= 1000) counter = millis();
    if (counter - counterold <= 1000) {
      if (!ShowServiceInformation && !SlideShowView && !ChannelListView) {
        ShowServiceInfo();
        ShowServiceInformation = true;
      } else {
        BuildDisplay();
      }
    } else {
      doStandby();
    }
  }
  while (digitalRead(STANDBYBUTTON) == LOW);
}
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

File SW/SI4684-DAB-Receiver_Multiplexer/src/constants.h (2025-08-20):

#ifndef CONSTANTS_H
#define CONSTANTS_H

/*#define ROTARY_PIN_A    11//27
#define ROTARY_PIN_B    12//34
#define ROTARY_PIN_2A   13//33
#define ROTARY_PIN_2B   11//32
#define ROTARY_BUTTON   12//25
#define ROTARY_BUTTON2  13//35*/
#define STANDBYBUTTON   11//36
//#define SLBUTTON        12//26
//#define MODEBUTTON      21//39
#define CONTRASTPIN     2//2



// TCA9554 I2C address (default is 0x20, can be 0x20-0x27 depending on A0-A2 pins)
#define TCA9554_ADDRESS 0x20

// TCA9554 Register addresses
#define TCA9554_INPUT_REG     0x00  // Input port register
#define TCA9554_OUTPUT_REG    0x01  // Output port register  
#define TCA9554_POLARITY_REG  0x02  // Polarity inversion register
#define TCA9554_CONFIG_REG    0x03  // Configuration register

// Pin assignments on TCA9554 (P0-P7)
#define ENCODER_A_PIN    7  // P0 - Encoder A signal
#define ENCODER_B_PIN    5  // P1 - Encoder B signal
#define ENCODER_BTN_PIN  6  // P2 - Encoder button

#define ENCODER2_A_PIN    4  // P0 - Encoder A signal
#define ENCODER2_B_PIN    1  // P1 - Encoder B signal
#define ENCODER2_BTN_PIN  0  // P2 - Encoder button

#define ENCODER_BTN3_PIN  2  // P2 - Encoder button
#define ENCODER_BTN4_PIN  3  // P2 - Encoder button

#define INT_PIN          43  // Arduino interrupt pin connected to TCA9554 INT




#define ITEM_GAP        20
#define ITEM1           3
#define ITEM2           23
#define ITEM3           43
#define ITEM4           63
#define ITEM5           83
#define ITEM6           103
#define ITEM7           123
#define ITEM8           143
#define ITEM9           163
#define ITEM10          183

// EEPROM index defines
#define EE_PRESETS_CNT              99
#define EE_PRESETS_FREQUENCY        255
#define EE_CHECKBYTE_VALUE          2 // 0 ~ 255,add new entry, change for new value

#define EE_TOTAL_CNT                2614
#define EE_BYTE_CHECKBYTE           0
#define EE_BYTE_LANGUAGE            1
#define EE_BYTE_CONTRASTSET         2
#define EE_BYTE_DISPLAYFLIP         3
#define EE_BYTE_ROTARYMODE          4
#define EE_BYTE_TUNEMODE            5
#define EE_BYTE_BUFFERSLIDESHOW     6
#define EE_BYTE_UNIT                7
#define EE_BYTE_DABFREQ             8
#define EE_BYTE_VOLUME              9
#define EE_BYTE_MEMORYPOS           10
#define EE_BYTE_THEME               11
#define EE_BYTE_AUTOSLIDESHOW       12
#define EE_BYTE_TOT                 13
#define EE_UINT32_SERVICEID         14
#define EE_CHAR17_SERVICENAME       22 // 17 bytes!
#define EE_PRESETS_FREQ_START       39
#define EE_PRESETS_SERVICEID_START  138
#define EE_PRESETS_NAME_START       930
// End of EEPROM index defines

static const char* const unitString[] = {"dBμV", "dBf", "dBm"};
static const char* const Theme[] = {"Elegant", "GoldenDusk", "Vibrant", "Serenity", "Luminous", "Radiant", "Sunset"};

enum RADIO_TUNE_MODE {
  TUNE_MAN, TUNE_AUTO, TUNE_MEM
};

enum RADIO_MEM_POS_STATUS {
  MEM_DARK, MEM_NORMAL, MEM_EXIST
};

#endif

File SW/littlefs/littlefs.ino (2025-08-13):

#include "LittleFS.h"
 
void setup() {
  Serial.begin(115200);
  delay(500);
  
  if(!LittleFS.begin()){
    Serial.println("An Error has occurred while mounting LittleFS");
    return;
  }
  
  File file = LittleFS.open("/test_example.txt", "r");
  if(!file){
    Serial.println("Failed to open file for reading");
    return;
  }
  
  Serial.println("File Content:");
  while(file.available()){
    Serial.write(file.read());
  }
  file.close();
}
 
void loop() {

}

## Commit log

2025-06-04 Add files via upload
    work in progress. not finished
    [SI4684-B_Cu.gbr, SI4684-B_Mask.gbr, SI4684-B_Paste.gbr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]
2025-06-04 Add files via upload
    fixed some layout issues. still work in progress
    [SI4684-B_Cu.gbr, SI4684-B_Mask.gbr, SI4684-B_Paste.gbr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]
2025-06-05 Add files via upload
    added Display connector
    [SI4684-B_Cu.gbr, SI4684-B_Mask.gbr, SI4684-B_Paste.gbr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]
2025-06-10 Delete Kicad/Controller directory
    not needed any more
    [SI4684 controller.kicad_pcb, SI4684 controller.kicad_sch]
2025-06-10 Add files via upload
    - Added second Rotary encoder
    - Removed need for Motherboard
    - Removed Switch P4 (Slideshow Switch)
    - Did a lot of Rerouting
    - Performed some DRC Checks
    (still not final)... work in Progress
    [SI4684.kicad_pcb, SI4684.kicad_sch]
2025-08-22 Add files via upload
    Beware... 2 parts missing 2.7pF and 2x 270pf
    and some for the backside
    [JLCPCBbom.xls]
2025-08-22 Delete Kicad/Controller directory
    not neeeded
    [sensor_puck.kicad_pcb, sensor_puck.kicad_sch, sensor_puck.step]

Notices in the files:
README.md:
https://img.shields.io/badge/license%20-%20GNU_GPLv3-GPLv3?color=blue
